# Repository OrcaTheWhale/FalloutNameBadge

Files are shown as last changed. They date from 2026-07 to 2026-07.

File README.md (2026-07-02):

# FalloutNameBadge

Slack: OrcaTheWhale

I am late to the deadline, and folders aren't uploading(for some reason), so that's why the repo is a little mess right now.

This name badge is an over-engineered badge to light up and provide a unique NFC tag depending on the tilt.

Utilizing an RP2040 and essentially being a clone board without breaking GPIOs, the FalloutNameBadge utilizes an accelerometer to detect tilt, and based on the tilt, lights up one of four LED's, and one of four links.

IMPORTANT INFORMATION FOR STAFF.
- IDK WHY MY PCBS DO THIS; THE PCB IS 2 LAYERS ONLY, AND SWITCH VIAS TO TENTED.

GO PCB BARE ONLY!!! HOW IS IT POSSIBLE TO RUN OUT OF RP2040S JLCPCB???

Front:



Back:



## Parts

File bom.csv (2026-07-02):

Designator | Footprint | Quantity | Value | LCSC Part #
C1, C10, C11, C17, C18, C19, C2, C3, C4, C5, C6, C7, C8 | 0402 | 13 | 0.1uF
C12, C9 | 0402 | 2 | 1uF
C13, C14 | 0603 | 2 | 10uF
C15, C16 | 0402 | 2 | 36pF
D1, D2, D3, D4 | 0402 | 4 | LED
J1 | USB_C_Receptacle_HRO_TYPE-C-31-M-12 | 1 | USB_C_Receptacle_USB2.0_14P
R1, R2 | 0402 | 2 | 5.1K
R10, R11, R12, R13, R5, R7 | 0402 | 6 | 1K
R3, R4 | 0402 | 2 | 27
R6 | 0402 | 1 | 10.7K
R8, R9 | 0402 | 2 | 4.7K
SW1 | SW_PUSH_6mm | 1 | SW_Push
U1 | QFN-56-1EP_7x7mm_P0.4mm_EP3.2x3.2mm | 1 | RP2040
U2 | SOT-23 | 1 | MCP1700x-330xxTT
U3 | Winbond_USON-8-1EP_3x2mm_P0.5mm_EP0.2x1.6mm | 1 | W25Q128JVS
U4 | LGA-16_3x3mm_P0.5mm_LayoutBorder3x5y | 1 | LIS3DH
U5 | DFN-8-1EP_3x2mm_P0.5mm_EP1.36x1.46mm | 1 | ST25DV04K-IER8C3
Y1 | Crystal_SMD_3225-4Pin_3.2x2.5mm | 1 | 12MHz

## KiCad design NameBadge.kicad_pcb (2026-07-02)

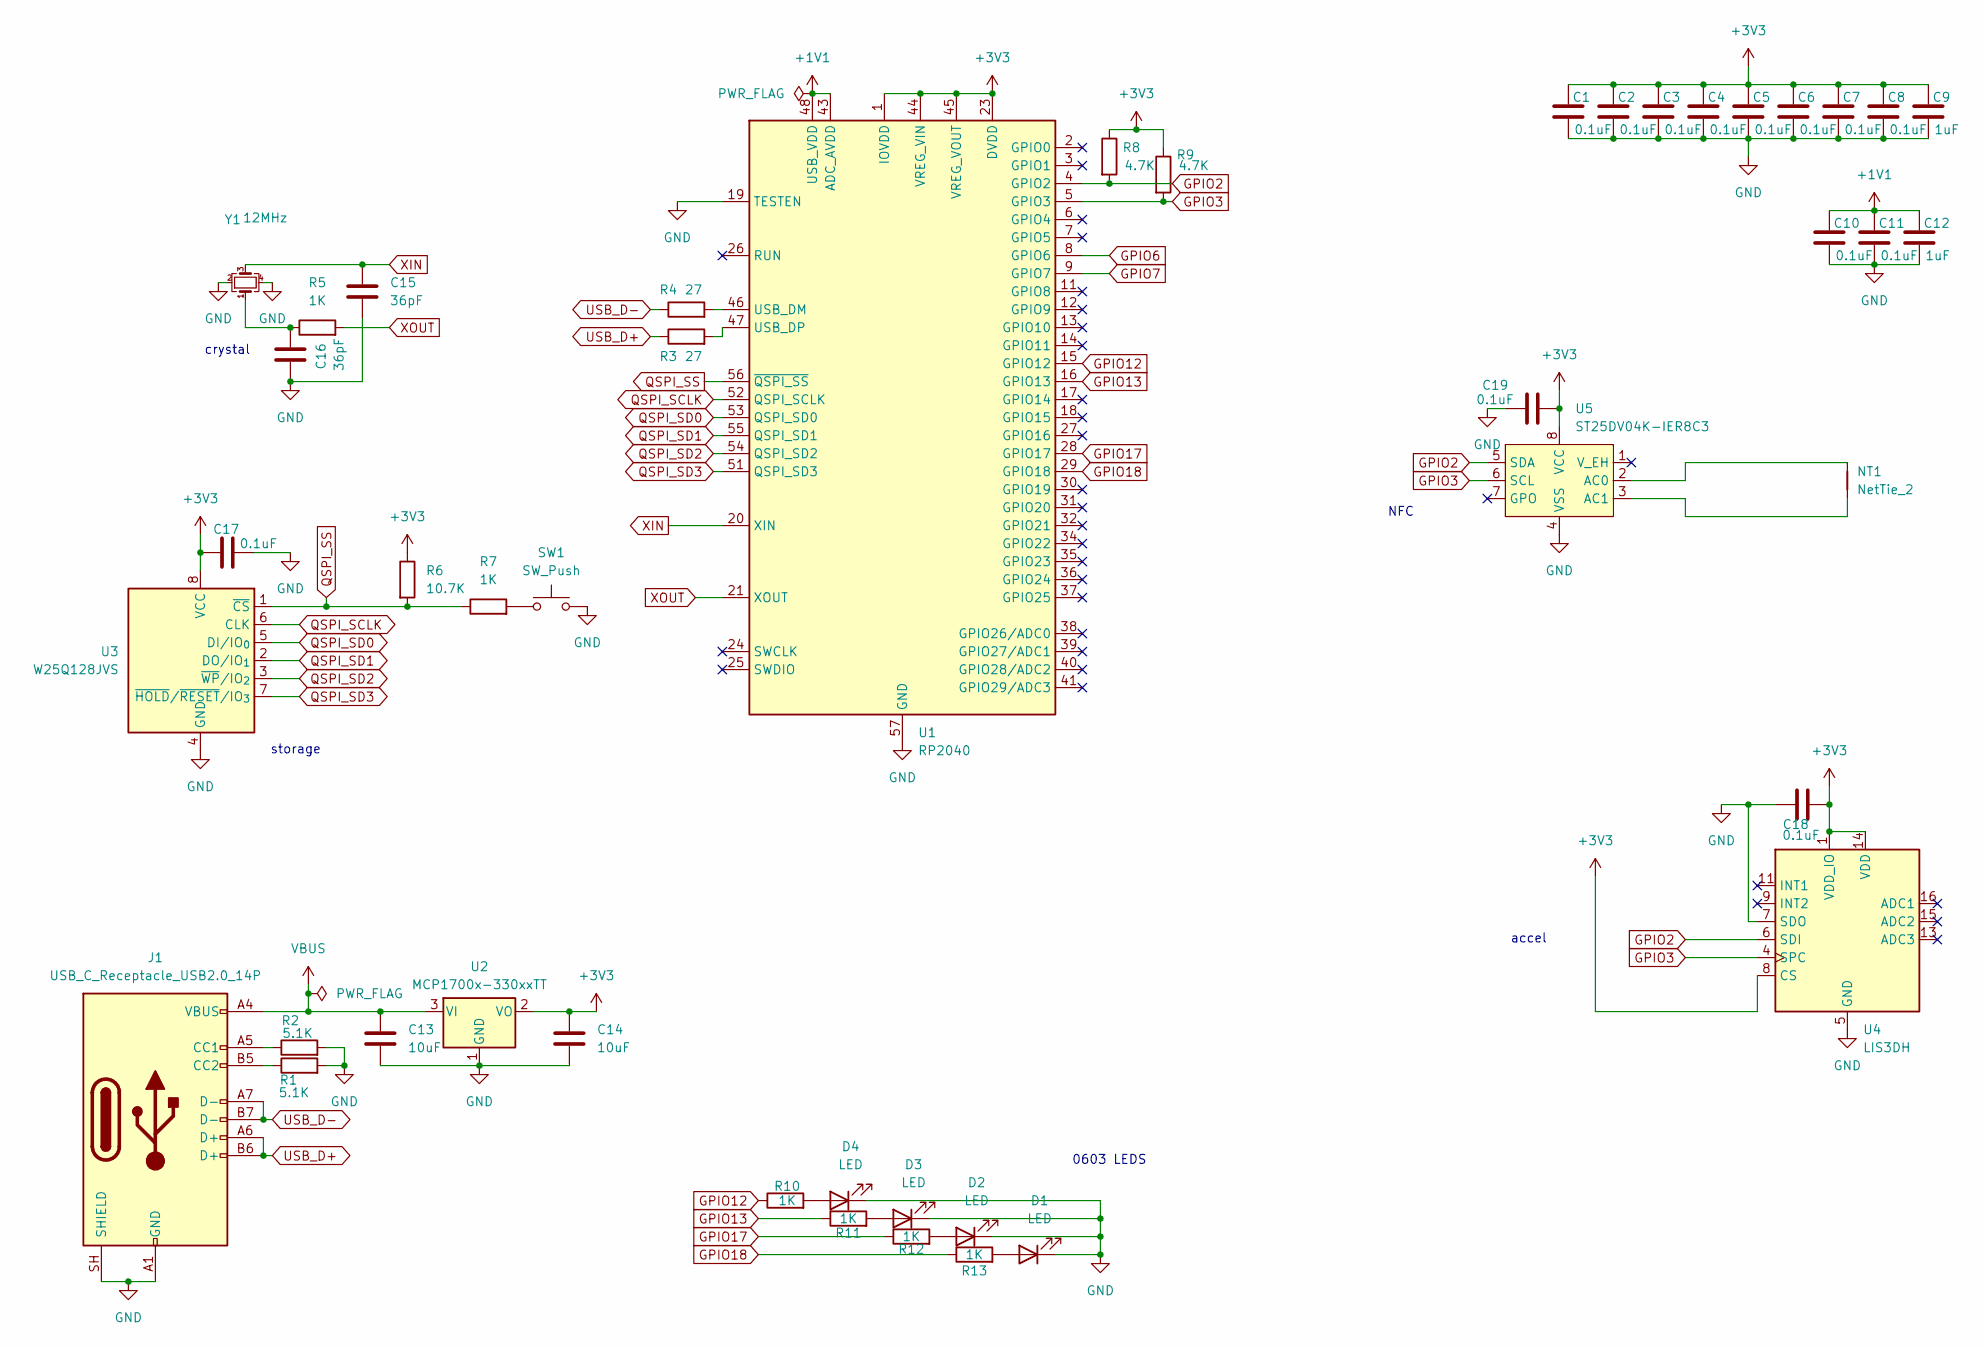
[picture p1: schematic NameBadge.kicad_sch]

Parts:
C1, C2, C3, C4, C5, C6, C7, C8, C10, C11: 0.1uF; C_0402_1005Metric_Pad0.74x0.62mm_HandSolder
C9, C12: 1uF; C_0402_1005Metric_Pad0.74x0.62mm_HandSolder
C13, C14: 10uF; C_0603_1608Metric
C15, C16: 36pF; C_0402_1005Metric
C17, C18, C19: 0.1uF; C_0402_1005Metric
D1, D2, D3, D4: LED; LED_0402_1005Metric
J1: USB_C_Receptacle_USB2.0_14P; USB_C_Receptacle_HRO_TYPE-C-31-M-12
NT1: NetTie_2; NetTie-2_SMD_Pad0.5mm
R1, R2: 5.1K; R_0402_1005Metric
R3, R4: 27; R_0402_1005Metric
R5, R7, R10, R11, R12, R13: 1K; R_0402_1005Metric
R6: 10.7K; R_0402_1005Metric
R8, R9: 4.7K; R_0402_1005Metric
SW1: SW_Push; SW_PUSH_6mm
U1: RP2040; QFN-56-1EP_7x7mm_P0.4mm_EP3.2x3.2mm
U2: MCP1700x-330xxTT; SOT-23
U3: W25Q128JVS; Winbond_USON-8-1EP_3x2mm_P0.5mm_EP0.2x1.6mm
U4: LIS3DH; LGA-16_3x3mm_P0.5mm_LayoutBorder3x5y
U5: ST25DV04K-IER8C3; DFN-8-1EP_3x2mm_P0.5mm_EP1.36x1.46mm
Y1: 12MHz; Crystal_SMD_3225-4Pin_3.2x2.5mm

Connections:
+1V1: C10.1, C11.1, C12.1, U1.43 (ADC_AVDD), U1.48 (USB_VDD)
+3V3: C1.1, C2.1, C3.1, C4.1, C5.1, C6.1, C7.1, C8.1, C9.1, C14.1, C17.1, C18.2, C19.2, R6.1, R8.1, R9.1, U1.1 (IOVDD), U1.10 (IOVDD), U1.22 (IOVDD), U1.23 (DVDD), U1.33 (IOVDD), U1.42 (IOVDD), U1.44 (VREG_VIN), U1.45 (VREG_VOUT), U1.49 (IOVDD), U1.50 (DVDD), U2.2 (VO), U3.8 (VCC), U4.1 (VDD_IO), U4.8 (CS), U4.14 (VDD), U5.8 (VCC)
GND: C1.2, C2.2, C3.2, C4.2, C5.2, C6.2, C7.2, C8.2, C9.2, C10.2, C11.2, C12.2, C13.2, C14.2, C15.1, C16.1, C17.2, C18.1, C19.1, D1.1 (K), D2.1 (K), D3.1 (K), D4.1 (K), J1.A1 (GND), J1.A12 (GND), J1.B1 (GND), J1.B12 (GND), J1.SH (SHIELD), R1.2, R2.2, SW1.2, U1.19 (TESTEN), U1.57 (GND), U2.1 (GND), U3.4 (GND), U4.5 (GND), U4.7 (SDO), U4.10 (GND), U4.12 (GND), U5.4 (VSS), Y1.2 (G), Y1.4 (G)
GPIO2: R8.2, U1.4 (GPIO2), U4.6 (SDI), U5.5 (SDA)
GPIO3: R9.2, U1.5 (GPIO3), U4.4 (SPC), U5.6 (SCL)
GPIO6: U1.8 (GPIO6)
GPIO7: U1.9 (GPIO7)
GPIO12: R10.1, U1.15 (GPIO12)
GPIO13: R11.1, U1.16 (GPIO13)
GPIO17: R12.1, U1.28 (GPIO17)
GPIO18: R13.1, U1.29 (GPIO18)
unnamed: C16.2, R5.1, Y1.1
unnamed: D1.2 (A), R13.2
unnamed: D2.2 (A), R12.2
unnamed: D3.2 (A), R11.2
unnamed: D4.2 (A), R10.2
unnamed: J1.A5 (CC1), R2.1
unnamed: J1.B5 (CC2), R1.1
unnamed: NT1.2, U5.2 (AC0)
unnamed: NT1.1, U5.3 (AC1)
unnamed: R7.2, SW1.1
unnamed: R4.2, U1.46 (USB_DM)
unnamed: R3.2, U1.47 (USB_DP)
QSPI_SCLK: U1.52 (QSPI_SCLK), U3.6 (CLK)
QSPI_SD0: U1.53 (QSPI_SD0), U3.5 (DI/IO_{0})
QSPI_SD1: U1.55 (QSPI_SD1), U3.2 (DO/IO_{1})
QSPI_SD2: U1.54 (QSPI_SD2), U3.3 (~WP/IO_{2})
QSPI_SD3: U1.51 (QSPI_SD3), U3.7 (~HOLD/~RESET/IO_{3})
QSPI_SS: R6.2, R7.1, U1.56 (~QSPI_SS), U3.1 (~CS)
USB_D+: J1.A6 (D+), J1.B6 (D+), R3.1
USB_D-: J1.A7 (D-), J1.B7 (D-), R4.1
VBUS: C13.1, J1.A4 (VBUS), J1.A9 (VBUS), J1.B4 (VBUS), J1.B9 (VBUS), U2.3 (VI)
XIN: C15.2, U1.20 (XIN), Y1.3
XOUT: R5.2, U1.21 (XOUT)

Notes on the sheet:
storage
accel
crystal
0603 LEDS
NFC

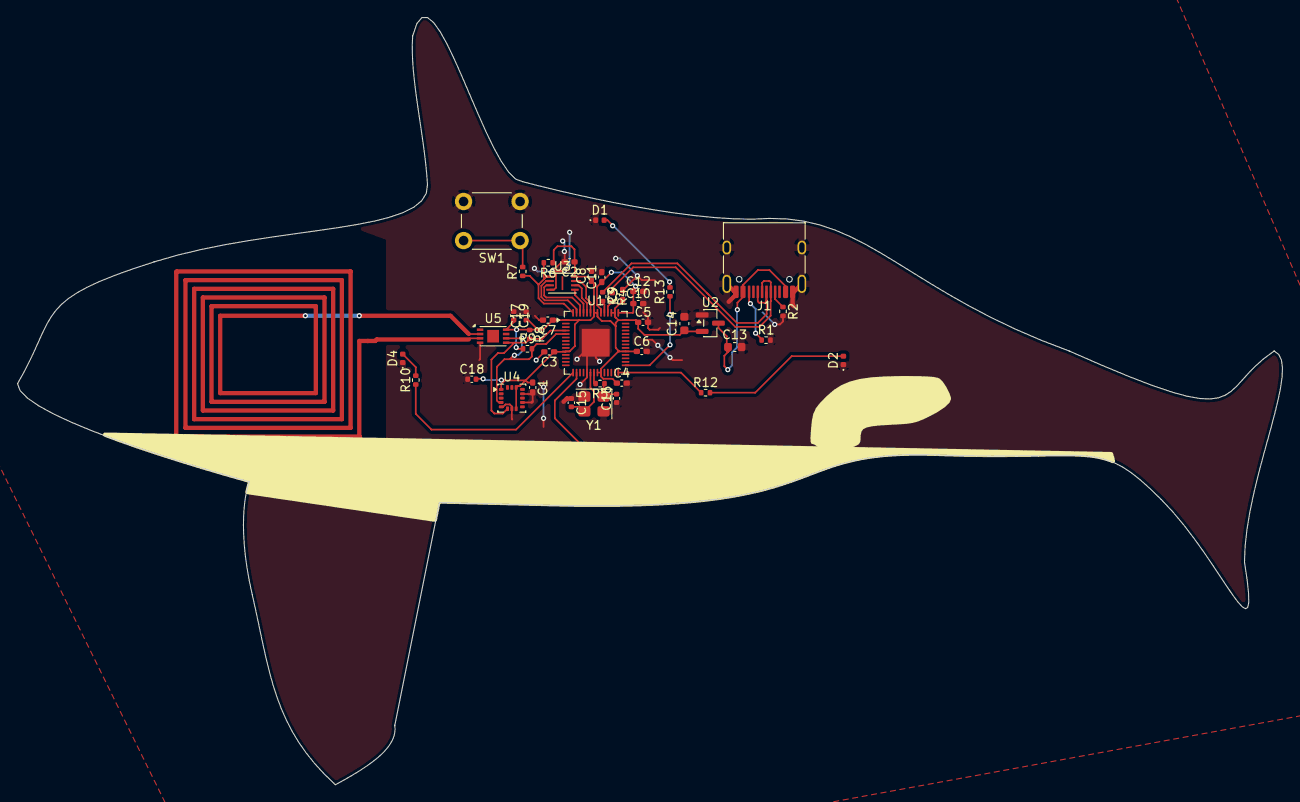
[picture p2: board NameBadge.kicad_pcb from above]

Board: 4 copper layers, 145.5 x 88.3 mm, 45 parts (0 on the bottom side), 32 nets.
